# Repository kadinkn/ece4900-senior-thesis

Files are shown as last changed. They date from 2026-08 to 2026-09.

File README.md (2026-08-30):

# ECE4900 Floating Photovoltaic Power System

Senior Thesis project focused on designing and testing a small-scale floating photovoltaic power system with:

- Custom synchronous buck converter
- MPPT control
- STM32G474 microcontroller
- PV and battery voltage/current sensing
- Temperature sensing
- Real-time UART telemetry
- Input and output protection
- Battery charging interface

## Project Status

Current work includes:

- Buck converter power stage
- Gate driver circuitry
- 12 V auxiliary supply
- 3.3 V MCU supply
- STM32 support circuitry
- SWD programming/debug interface
- PWM control connections
- PV voltage/current sensing
- Battery voltage/current sensing
- Temperature sensing
- UART telemetry
- PV input protection
- Battery output protection

PCB layout, design-rule checks, manufacturing files, firmware, and hardware testing are still in progress.

## Main Hardware

- MCU: STM32G474CBT6TR
- Gate Driver: TI UCC27301A
- Buck MOSFETs: TI CSD18540Q5B
- PV Panel: Renogy 100 W
- Battery: Renogy 12.8 V 20 Ah LiFePO4

## Repository Files

Open the `.kicad_pro` file in KiCad to load the project.

The repository will eventually contain:

- KiCad schematic
- PCB layout
- BOM
- Datasheets/reference documents
- Manufacturing files
- Firmware
- Testing documentation

## Notes

This is a Rev 0 prototype design and is still under active development and review.

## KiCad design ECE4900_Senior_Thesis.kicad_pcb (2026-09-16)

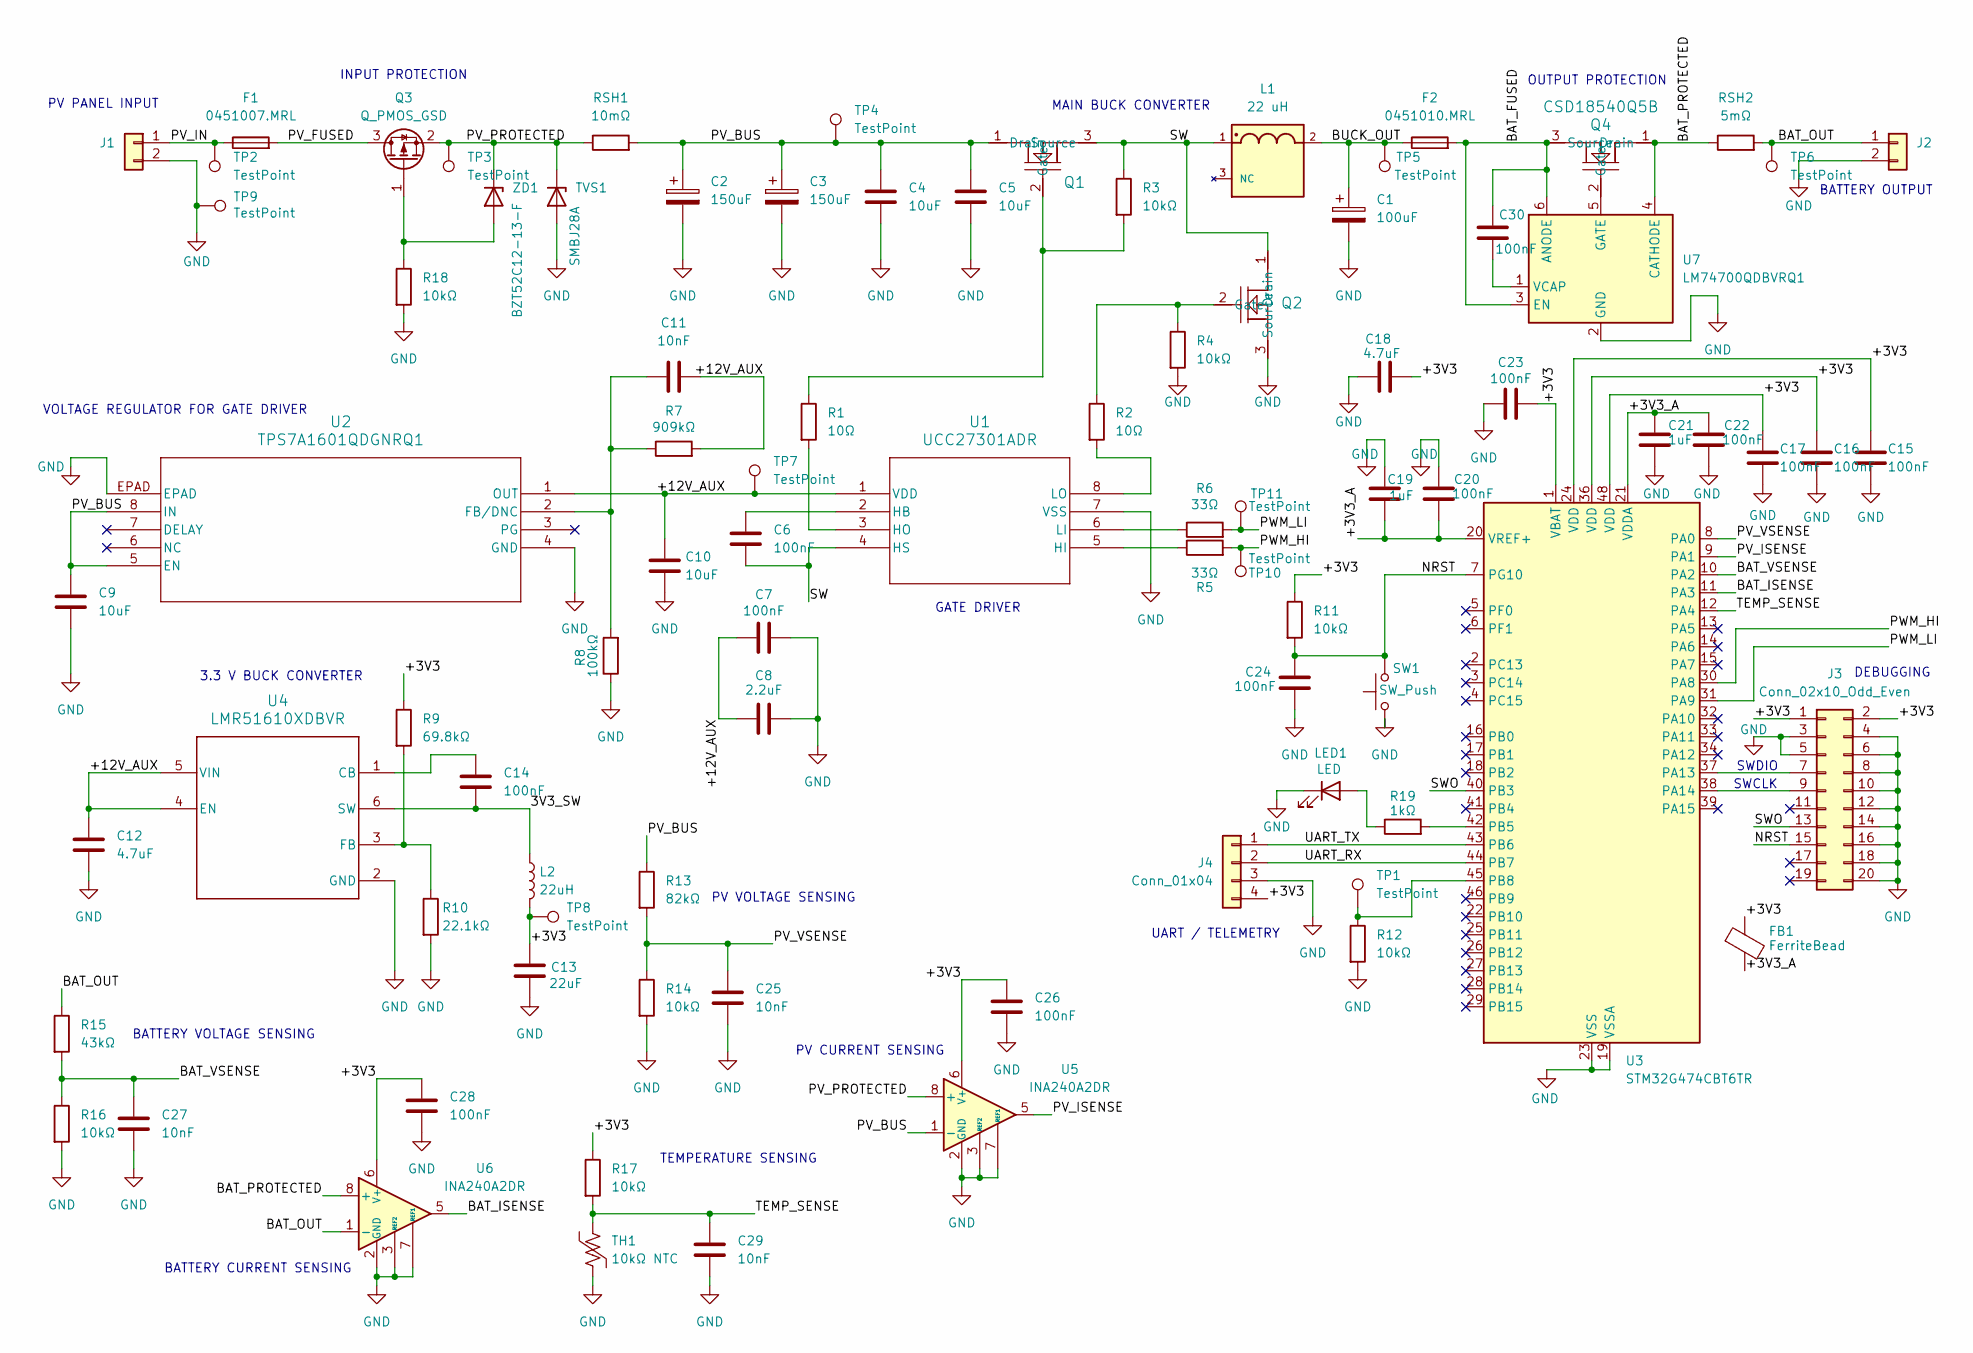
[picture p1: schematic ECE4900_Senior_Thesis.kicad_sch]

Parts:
C1: 100uF; CP_Elec_8x6.9
C2, C3: 150uF; CP_Elec_10x12.5
C4, C5, C9, C10: 10uF; C_1210_3225Metric
C6, C7, C14, C15, C16, C17, C20, C22, C23, C24, C26, C28, C30: 100nF; C_0603_1608Metric
C8: 2.2uF; C_0805_2012Metric
C11, C25, C27, C29: 10nF; C_0603_1608Metric
C12: 4.7uF; C_1206_3216Metric
C13: 22uF; C_1210_3225Metric
C18: 4.7uF; C_0805_2012Metric
C19, C21: 1uF; C_0603_1608Metric
F1: 0451007.MRL; Fuse_Littelfuse-NANO2-451_453
F2: 0451010.MRL; Fuse_Littelfuse-NANO2-451_453
FB1: FerriteBead; L_0603_1608Metric
J1, J2: 1757242; PhoenixContact_MSTBA_2,5_2-G-5,08_1x02_P5.08mm_Horizontal
J3: Conn_02x10_Odd_Even; IDC-Header_2x10_P2.54mm_Vertical
J4: Conn_01x04; PinHeader_1x04_P2.54mm_Vertical
L1: 22 uH; CSCF2014-220MC; PARTREV 05/31/2024
L2: 22uH; IND_1273AS-H-220M=P3
LED1: LED; LED_0603_1608Metric
Q1, Q2, Q4: CSD18540Q5B
Q3: Q_PMOS_GSD; Diodes_PowerDI3333-8
R1, R2: 10Ω; R_0805_2012Metric
R3, R4, R11, R12, R14, R16, R17, R18: 10kΩ; R_0603_1608Metric
R5, R6: 33Ω; R_0603_1608Metric
R7: 909kΩ; R_0603_1608Metric
R8: 100kΩ; R_0603_1608Metric
R9: 69.8kΩ; R_0603_1608Metric
R10: 22.1kΩ; R_0603_1608Metric
R13: 82kΩ; R_0603_1608Metric
R15: 43kΩ; R_0603_1608Metric
R19: 1kΩ; R_0603_1608Metric
RSH1: 10mΩ; KRL3264E-C-R010-F-T1
RSH2: 5mΩ; RESC6432X90N
SW1: SW_Push; SW_PUSH_6mm_H4.3mm
TH1: 10kΩ NTC; R_0603_1608Metric
TP1, TP2, TP3, TP4, TP5, TP6, TP7, TP8, TP9, TP10, TP11: TestPoint; TestPoint_Keystone_5000-5004_Miniature
TVS1: SMBJ28A; D_SMB
U1: UCC27301ADR
U2: TPS7A1601QDGNRQ1; DGN8_1P92X1P6_TEX
U3: STM32G474CBT6TR; LQFP-48_7x7mm_P0.5mm
U4: LMR51610XDBVR; DBV0006A-IPC_A
U5, U6: INA240A2DR; SOIC-8_3.9x4.9mm_P1.27mm
U7: LM74700QDBVRQ1; SOT-23-6
ZD1: BZT52C12-13-F; D_SOD-123

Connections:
/3V3_SW: C14.2, L2.1, U4.6 (SW)
/+3V3: C13.1, C15.1, C16.1, C17.1, C18.2, C23.2, C26.1, C28.1, FB1.1, J3.1, J3.2, J4.4, L2.2, R9.1, R11.1, R17.1, TP8.1 (1_1), U3.1 (VBAT), U3.24 (VDD), U3.36 (VDD), U3.48 (VDD), U5.6 (V+), U6.6 (V+)
/+3V3_A: C19.2, C20.2, C21.1, C22.1, FB1.2, U3.20 (VREF+), U3.21 (VDDA)
/+12V_AUX: C7.1, C8.1, C10.1, C11.2, C12.1, R7.2, TP7.1 (1_1), U1.1 (VDD), U2.1 (OUT), U4.4 (EN), U4.5 (VIN)
/BAT_FUSED: C30.1, F2.2, Q4.3 (Source), U7.3 (EN), U7.6 (ANODE)
/BAT_ISENSE: U3.11 (PA3), U6.5
/BAT_OUT: J2.1, R15.1, RSH2.2, TP6.1 (1_1), U6.1 (-)
/BAT_PROTECTED: Q4.1 (Drain), RSH2.1, U6.8 (+), U7.4 (CATHODE)
/BAT_VSENSE: C27.1, R15.2, R16.1, U3.10 (PA2)
/BUCK_OUT: C1.1, F2.1, L1.2, TP5.1 (1_1)
/NRST: C24.1, J3.15, R11.2, SW1.2, U3.7 (PG10)
/PV_BUS: C2.1, C3.1, C4.1, C5.1, C9.1, Q1.1 (Drain), R13.1, RSH1.2, TP4.1 (1_1), U2.5 (EN), U2.8 (IN), U5.1 (-)
/PV_FUSED: F1.2, Q3.3 (D)
/PV_IN: F1.1, J1.1, TP2.1 (1_1)
/PV_ISENSE: U3.9 (PA1), U5.5
/PV_PROTECTED: Q3.2 (S), RSH1.1, TP3.1 (1_1), TVS1.1 (K), U5.8 (+), ZD1.1 (K)
/PV_VSENSE: C25.1, R13.2, R14.1, U3.8 (PA0)
/PWM_HI: R5.2, TP10.1 (1_1), U3.30 (PA8)
/PWM_LI: R6.2, TP11.1 (1_1), U3.31 (PA9)
/SW: C6.2, L1.1, Q1.3 (Source), Q2.1 (Drain), R3.1, U1.4 (HS)
/SWO: J3.13, U3.40 (PB3)
/TEMP_SENSE: C29.1, R17.2, TH1.1, U3.12 (PA4)
/UART_RX: J4.2, U3.44 (PB7)
/UART_TX: J4.1, U3.43 (PB6)
GND: C1.2, C2.2, C3.2, C4.2, C5.2, C7.2, C8.2, C9.2, C10.2, C12.2, C13.2, C15.2, C16.2, C17.2, C18.1, C19.1, C20.1, C21.2, C22.2, C23.1, C24.2, C25.2, C26.2, C27.2, C28.2, C29.2, J1.2, J2.2, J3.3, J3.4, J3.5, J3.6, J3.8, J3.10, J3.12, J3.14, J3.16, J3.18, J3.20, J4.3, LED1.1 (K), Q2.3 (Source), R4.2, R8.1, R10.2, R12.2, R14.2, R16.2, R18.2, SW1.1, TH1.2, TP9.1 (1_1), TVS1.2 (A), U1.7 (VSS), U2.4 (GND), U2.EPAD, U3.19 (VSSA), U3.23 (VSS), U3.35 (VSS), U3.47 (VSS), U4.2 (GND), U5.2 (GND), U5.3 (REF2), U5.4 (GND), U5.7 (REF1), U6.2 (GND), U6.3 (REF2), U6.4 (GND), U6.7 (REF1), U7.2 (GND)
unnamed: J3.7, U3.37 (PA13)
unnamed: J3.9, U3.38 (PA14)
unnamed: LED1.2 (A), R19.1
unnamed: Q1.2 (Gate), R1.1, R3.2
unnamed: Q2.2 (Gate), R2.1, R4.1
unnamed: Q3.1 (G), R18.1, ZD1.2 (A)
unnamed: Q4.2 (Gate), U7.5 (GATE)
unnamed: C6.1, U1.2 (HB)
unnamed: R5.1, U1.5 (HI)
unnamed: R1.2, U1.3 (HO)
unnamed: R6.1, U1.6 (LI)
unnamed: R2.2, U1.8 (LO)
unnamed: C11.1, R7.1, R8.2, U2.2 (FB/DNC)
unnamed: R19.2, U3.42 (PB5)
unnamed: R12.1, TP1.1 (1_1), U3.45 (PB8)
unnamed: C14.1, U4.1 (CB)
unnamed: R9.2, R10.1, U4.3 (FB)
unnamed: C30.2, U7.1 (VCAP)

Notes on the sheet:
VOLTAGE REGULATOR FOR GATE DRIVER
DEBUGGING
PV VOLTAGE SENSING
PV CURRENT SENSING
PV PANEL INPUT
3.3 V BUCK CONVERTER
BATTERY CURRENT SENSING
TEMPERATURE SENSING
SWCLK
GATE DRIVER
OUTPUT PROTECTION
BATTERY VOLTAGE SENSING
BATTERY OUTPUT
MAIN BUCK CONVERTER
INPUT PROTECTION
UART / TELEMETRY
SWDIO

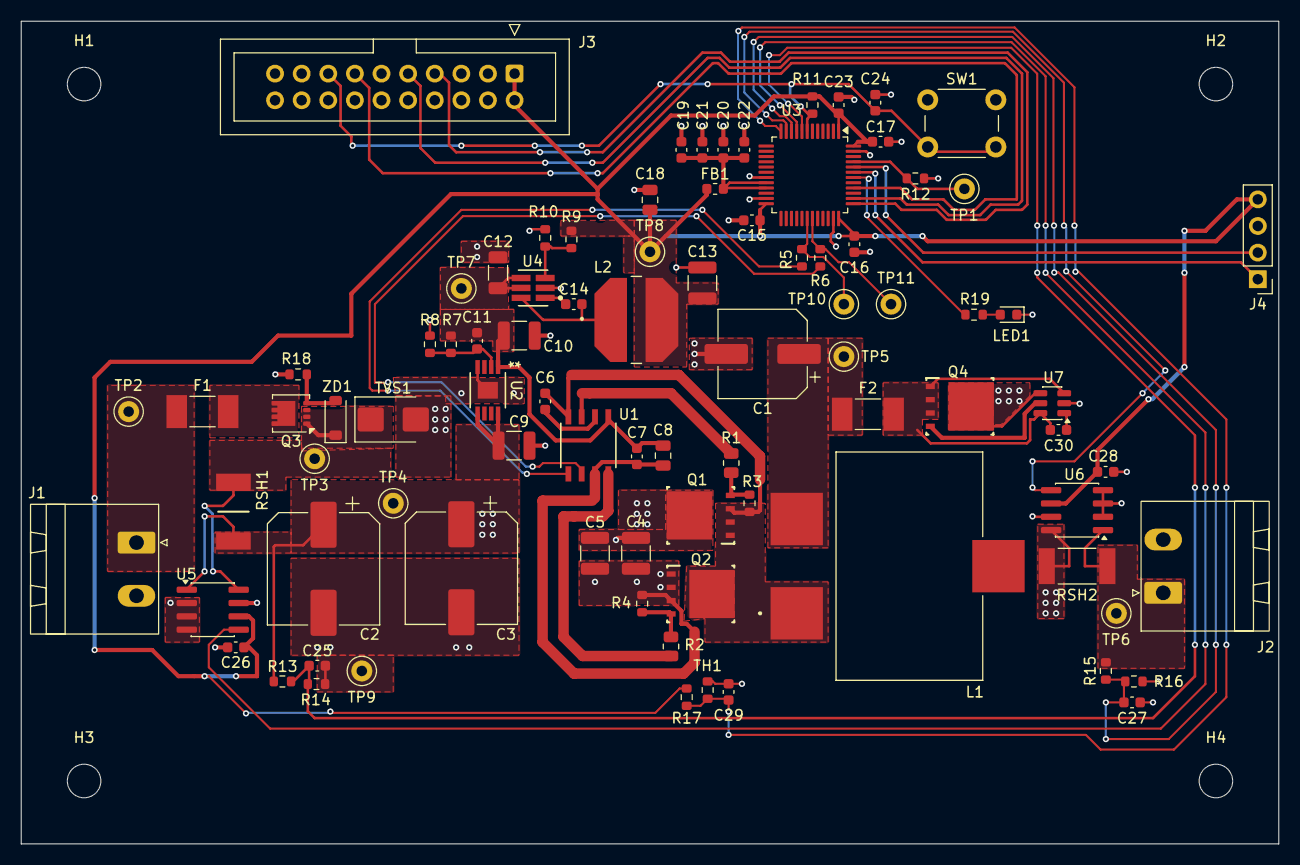
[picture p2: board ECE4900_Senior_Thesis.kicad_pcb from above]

Board: 4 copper layers, 120.0 x 78.5 mm, 91 parts (0 on the bottom side), 43 nets.

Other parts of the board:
H1, H2, H3, H4: MountingHole_3.2mm_M3

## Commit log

2026-08-30 Upload Rev 0 Schematic
    Most of the schematic finished. Still need to: add test points, add status LEDs, do full schematic audit
    [ECE4900_Senior_Thesis.kicad_pcb, ECE4900_Senior_Thesis.kicad_sch]
2026-08-31 Finalized schematic and began assigning footprints
    [ECE4900_Senior_Thesis.kicad_pcb, ECE4900_Senior_Thesis.kicad_sch]
2026-09-01 Added last two footprints
    L1 and RSH1
2026-09-07 Added 3D Footprints, Ready for Layout
    Contains new "3dmodels" folder with all 3d models not previously imported. Also contains fixes for different footprints. Everything is ready for layout.
2026-09-16 Preliminary Layout Finished
    Further pre-fab inspection is neccessary
    [ECE4900_Senior_Thesis.kicad_pcb, ECE4900_Senior_Thesis.kicad_sch]
